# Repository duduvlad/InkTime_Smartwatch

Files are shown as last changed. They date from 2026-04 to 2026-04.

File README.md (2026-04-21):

# InkTime Smartwatch

Un smartwatch open-source cu ecran E-Paper, construit în jurul SoC-ului Nordic nRF52840. Proiectul acoperă etapa de Engineering Validation (EVT): design-ul hardware complet (schematic + PCB), fișierele de fabricație și modelul 3D al ansamblului.

## Cuprins

- [Diagrama Bloc](#diagrama-bloc)
- [Descriere Hardware](#descriere-hardware)
- [Pinout nRF52840](#pinout-nrf52840)
- [Bill of Materials](#bill-of-materials)
- [Estimare Consum Energetic](#estimare-consum-energetic)
- [Decizii de Design și Constrângeri](#decizii-de-design-și-constrângeri)
- [Imagini](#imagini)
- [Structura Repository-ului](#structura-repository-ului)
- [Licență](#licență)

---

## Diagrama Bloc
 
```
                          ┌─────────────────────────────────┐
                          │         nRF52840 (U1)           │
                          │       SoC + BLE Radio           │
                          │                                 │
          ┌───────────────┤ P0.06 (SDA)     P0.02 (SCK)    ├──── SPI ────┐
          │  I2C Bus      │ P0.07 (SCL)     P0.03 (MOSI)   │             │
          │               │                 P0.05 (CS)      │             │
          │               │                 P0.15 (DC)      │             │
          │               │                 P0.16 (RST)     │             │
          │               │                 P0.17 (BUSY)    │             │
          │               │                                 │             │
          │               │ P0.13 ──── SW_UP (buton)        │    ┌────────┴────────┐
          │               │ P0.14 ──── SW_ENTER (buton)     │    │  E-Paper 1.54"  │
          │               │ P1.02 ──── SW_DOWN (buton)      │    │  (via FPC J1)   │
          │               │                                 │    └─────────────────┘
          │               │ P0.12 ──── HAPTIC_EN (DRV2605)  │
          │               │ P0.08 ──── IMU_INT1             │
          │               │ P1.08 ──── IMU_INT2             │
          │               │ P0.10 ──── ALERT (fuel gauge)   │
          │               │ P0.11 ──── PMIC_INT (charger)   │
          │               │ P1.01 ──── EPD_PWR (MOSFET)     │
          │               │                                 │
          │               │ D+/D- ──── USB-C (J4)           │
          │               │ SWDIO/SWDCLK ── Debug (J2)      │
          │               │                                 │
          │               │ ANT (H23) ── Antenă 2.4GHz      │
          │               └─────────────────────────────────┘
          │
     ┌────┴─────────────────────────────────────────────────┐
     │                   Magistrala I2C                      │
     │   (SDA = P0.06, SCL = P0.07, pull-up 3.3kΩ)         │
     ├──────────────┬──────────────┬─────────────┬──────────┤
     │              │              │             │          │
┌────┴────┐  ┌─────┴─────┐  ┌────┴────┐  ┌────┴────┐     │
│ BMA423  │  │ DRV2605   │  │MAX17048 │  │BQ25180  │     │
│  (IC3)  │  │  (IC2)    │  │  (U3)   │  │ (IC1)   │     │
│  IMU    │  │ Haptic    │  │  Fuel   │  │ Charger │     │
│         │  │ Driver    │  │  Gauge  │  │         │     │
└─────────┘  └───────────┘  └────┬────┘  └────┬────┘     │
                                 │             │          │
                            ┌────┴─────────────┴────┐     │
                   ┌───────>│  Baterie LiPo 250mAh  │     │
                   │        │    AKYGA LP502030      │     │
                   │        └───────────┬────────────┘     │
                   │                    │ VREG (SYS)       │
              USB-C (J4)         ┌──────┴──────┐           │
              VBUS ─────────────>│  RT6160     │           │
                                 │  (IC9)      │           │
                                 │  Buck-Boost │           │
                                 └──────┬──────┘           │
                                        │                  │
                                    3.3V Rail ─────────────┘
```

---

## Descriere Hardware

Inima proiectului este **nRF52840** — un SoC cu procesor ARM Cortex-M4F la 64 MHz, 1 MB Flash și 256 KB RAM, plus radio BLE 5.0 integrat. Pe lângă logica principală, el controlează direct toate perifericele de pe placă.

**Managementul energiei** funcționează într-un lanț: USB-C → BQ25180 (charger LiPo) → baterie AKYGA LP502030 (250 mAh, 3.7V) → RT6160 (buck-boost) → 3.3V stabil pentru tot sistemul. Tensiunea bateriei este monitorizată de un fuel gauge MAX17048, care trimite alerte prin I2C și pin-ul ALERT când bateria scade sub praguri configurabile. Charger-ul BQ25180 comunică și el pe I2C, permițând configurarea curentului de încărcare, iar pin-ul !INT semnalează evenimente (încărcare completă, erori termice, etc.).

**Afișajul** este un ecran E-Paper de 1.54" conectat printr-un flex cable (FPC de 24 pini, conector Molex 503480-2400). E-Paper-ul consumă curent doar la refresh și își menține imaginea fără alimentare. Alimentarea display-ului este controlată separat prin P1.01, care comandă un MOSFET P-channel (DMG2305UX-7) — astfel display-ul poate fi oprit complet pentru a economisi energie. Comunicația cu display-ul se face pe SPI, cu pini adiționali de control (DC, RST, BUSY).

**Senzorul de mișcare** BMA421/BMA423 (accelerometru triaxial, 12 biți) este pe magistrala I2C și oferă două ieșiri de întrerupere (INT1 pe P0.08 și INT2 pe P1.08). Este folosit pentru numărarea pașilor, detecția gesturilor (raise-to-wake) și orientarea ecranului. Pin-ul SDO al senzorului este legat la GND prin R3, ceea ce setează adresa I2C la 0x18.

**Feedback haptic**: un motor de vibrații controlat de DRV2605 (driver dedicat cu bibliotecă internă de efecte). Driverul primește comenzi pe I2C și este activat/dezactivat de P0.12 (EN). Ieșirile OUT+ și OUT- merg la motorul haptic (shaker), cu test pad-uri pe placă pentru debugging.

**Butoanele**: trei butoane push (UP, ENTER, DOWN) cu rezistențe de pull-up de 10kΩ la 3.3V și condensatoare de debouncing de 1µF pe fiecare. Sunt active pe LOW — apăsarea trage pinul la GND.

**Conectivitate BLE**: antena ceramică Johanson 2450AT18B100E, conectată la pinul ANT al nRF52840 printr-o rețea de impedanță matching (L1 = 3.9nH, C3 = 1pF, C4 = 1pF). Zona de sub antenă este decupată din toate cele trei planuri de masă.

**Debug/Programare**: interfață SWD (SWDIO, SWDCLK) rutată la conectorul Tag-Connect TC2030-IDC (J2) și la test pad-uri. Pin-ul SWO (P1.00) este disponibil și el pe test pad pentru trace output.

---

## Pinout nRF52840

Tabelul de mai jos detaliază fiecare pin utilizat al microcontroller-ului, cu referința la ball-ul din pachetul aQFN (7x7 mm, 73 pini).

| Pin nRF52840 | Ball | Net / Semnal | Destinație | Notă |
|:---|:---|:---|:---|:---|
| P0.00/XL1 | D2 | P0.00/XL1 | Crystal 32.768 kHz (X2) | Low-frequency clock |
| P0.01/XL2 | F2 | P0.01/XL2 | Crystal 32.768 kHz (X2) | Low-frequency clock |
| P0.02/AIN0 | A12 | SCK | E-Paper SPI Clock | SPI master |
| P0.03/AIN1 | B13 | MOSI | E-Paper SPI Data | SPI master |
| P0.05/AIN3 | K2 | EPD_CS | E-Paper Chip Select | SPI CS, active LOW |
| P0.06 | L1 | SDA | Magistrala I2C - Data | BQ25180, BMA423, DRV2605, MAX17048 |
| P0.07 | M2 | SCL | Magistrala I2C - Clock | Pull-up 3.3kΩ la 3V3 |
| P0.08 | N1 | IMU_INT1 | BMA423 Interrupt 1 | Step counter, gesture detection |
| P0.10/NFC2 | J24 | ALERT | MAX17048 Battery Alert | Active LOW |
| P0.11 | T2 | PMIC_INT | BQ25180 !INT | Semnalizare stare încărcare |
| P0.12 | U1 | HAPTIC_EN | DRV2605 Enable | Activare driver haptic |
| P0.13 | AD8 | SW_UP | Buton UP | Pull-up 10kΩ (R5), debounce 1µF (C30) |
| P0.14 | AC9 | SW_ENTER | Buton ENTER | Pull-up 10kΩ (R8), debounce 1µF (C31) |
| P0.15 | AD10 | EPD_DC | E-Paper Data/Command | HIGH = date, LOW = comandă |
| P0.16 | AC11 | EPD_RST | E-Paper Reset | Active LOW |
| P0.17 | AD12 | EPD_BUSY | E-Paper Busy | HIGH = display ocupat |
| P0.18/RESET | AC13 | RESET | System Reset | Rutat la TP_RESET și J2 |
| P1.00 | AD22 | SWO | Serial Wire Output | Debug trace, rutat la TP_SWO |
| P1.01 | Y23 | EPD_PWR | MOSFET gate (DMG2305UX) | Controlează alimentarea display-ului |
| P1.02 | W24 | SW_DOWN | Buton DOWN | Pull-up 10kΩ (R7), debounce 1µF (C29) |
| P1.08 | P2 | IMU_INT2 | BMA423 Interrupt 2 | Al doilea canal de întrerupere |
| D+ | AD6 | D+ | USB-C Data+ | Prin ESD protection (USBLC6-2SC6Y) |
| D- | AD4 | D- | USB-C Data- | Prin ESD protection (USBLC6-2SC6Y) |
| VBUS | AD2 | VBUS | USB VBUS sense | Detectare conexiune USB |
| SWDIO | AC24 | SWDIO | SWD Debug Data | Rutat la J2 (TC2030) și TP |
| SWDCLK | AA24 | SWDCLK | SWD Debug Clock | Rutat la J2 (TC2030) și TP |
| XC1 | B24 | - | Crystal 32 MHz (X1) | High-frequency clock |
| XC2 | A23 | - | Crystal 32 MHz (X1) | High-frequency clock |
| ANT | H23 | ANT | Rețea matching + Antenă | 2.4 GHz BLE |
| VDDH | Y2 | 3V3 | Alimentare high voltage | 3.3V |
| VDD (multiple) | W1, AD14, B1, A22, AD23 | 3V3 | Alimentare digitală | Fiecare cu condensator de decuplare |
| DCC | B3 | - | DC/DC inductor intern | L2 (10µH) |
| DEC1-6 | diverse | - | Decoupling intern nRF | Condensatoare conform datasheet-ului |

**Pini liberi** (neconectați, disponibili pentru extensii viitoare): P0.04, P0.09, P0.19–P0.31, P1.03–P1.07, P1.09–P1.15.

---

## Bill of Materials

### Componente principale

| Componentă | MFR Part Number | Descriere | JLCPCB Part # | Datasheet |
|:---|:---|:---|:---|:---|
| nRF52840 (U1) | NRF52840-QFAA | SoC BLE 5.0, ARM Cortex-M4F, aQFN-73 | [C190794](https://jlcpcb.com/partdetail/NordicSemicon-NRF52840_QIAAR/C190794) | [Nordic](https://infocenter.nordicsemi.com/pdf/nRF52840_PS_v1.8.pdf) |
| BQ25180 (IC1) | BQ25180YBGR | Charger LiPo, I2C configurabil, BGA-8 | [C3682423](https://jlcpcb.com/partdetail/TexasInstruments-BQ25180YBGR/C3682423) | [TI](https://www.ti.com/lit/ds/symlink/bq25180.pdf) |
| DRV2605 (IC2) | DRV2605YZFR | Haptic driver ERM/LRA, I2C, BGA-9 | [C81079](https://jlcpcb.com/partdetail/TexasInstruments-DRV2605YZFR/C81079) | [TI](https://www.ti.com/lit/ds/symlink/drv2605.pdf) |
| BMA423 (IC3) | BMA423 | Accelerometru triaxial, 12-bit, I2C, LGA-12 | [C437656](https://jlcpcb.com/parts) | [Bosch](https://www.bosch-sensortec.com/media/boschsensortec/downloads/datasheets/bst-bma423-ds000.pdf) |
| RT6160 (IC9) | RT6160AWSC | Buck-Boost DC/DC, I2C, WL-CSP-15 | [C20621404](https://jlcpcb.com/parts) | [Richtek](https://www.richtek.com/assets/product_file/RT6160A/DS6160A-05.pdf) |
| MAX17048 (U3) | MAX17048G+T10 | Fuel gauge LiPo, I2C, TDFN-8 | [C2682616](https://jlcpcb.com/partdetail/MaximIntegrated-MAX17048GT10/C2682616) | [Analog Devices](https://datasheets.maximintegrated.com/en/ds/MAX17048-MAX17049.pdf) |
| Antenă BLE (ANT1) | 2450AT18B100E | Antenă ceramică 2.4 GHz, 1206 | - | [Johanson](https://www.johansontechnology.com/datasheets/2450AT18B100/2450AT18B100.pdf) |
| FPC Connector (J1) | 503480-2400 | Molex 24-pin FPC, 0.5mm pitch | - | [Molex](https://www.molex.com/en-us/products/part-detail/5034802400) |
| USB-C (J4) | KH-TYPE-C-16P | Connector USB-C 16 pini, Kinghelm | - | [Kinghelm](https://www.snapeda.com/parts/KH-TYPE-C-16P/Kinghelm/view-part/) |
| Tag-Connect (J2) | TC2030-IDC | Conector debug SWD, 6 pini | - | [Tag-Connect](https://www.tag-connect.com/product/tc2030-idc) |
| ESD Protection (D3) | USBLC6-2SC6Y | TVS diode array, USB ESD, SOT-23-6 | - | [ST](https://www.st.com/resource/en/datasheet/usblc6-2.pdf) |
| MOSFET P-ch | DMG2305UX-7 | P-MOSFET, 20V/4.2A, SOT-23 | - | [Diodes Inc.](https://www.diodes.com/assets/Datasheets/DMG2305UX.pdf) |
| MOSFET N-ch (Q3) | SI1308EDL-T1-GE3 | N-MOSFET, 30V/1.5A, SC-70 | - | [Vishay](https://www.vishay.com/docs/63399/si1308edl.pdf) |
| Schottky Diodes (D2,D4,D5) | MBR0530 | 30V/0.5A, SOD-123 | - | [ON Semi](https://www.onsemi.com/pdf/datasheet/mbr0520-d.pdf) |
| Butoane (x3) | EVP-AKE31A | Push button, Panasonic | - | [Panasonic](https://industrial.panasonic.com/cdbs/www-data/pdf/ATV0000/ATV0000CE3.pdf) |
| Crystal 32 MHz (X1) | - | XTAL 2016 package | - | - |
| Crystal 32.768 kHz (X2) | - | XTAL 3215 package | - | - |
| Inductor (L7) | FTC252012SR47MBCA | 0.47µH, 2520, TDK | [C5832368](https://jlcpcb.com/partdetail/6763488-FTC252012SR47MBCA/C5832368) | [TDK](https://product.tdk.com/en/search/inductor/inductor/smd/info?part_no=FTC252012SR47MBCA) |

### Pasive (sumarizat)

| Tip | Valori | Capsulă | Cantitate |
|:---|:---|:---|:---|
| Rezistențe 0201 | 0.47Ω, 2.2Ω, 3.3kΩ, 5.1kΩ, 7.68kΩ, 10kΩ | 0201 (0.6x0.3mm) | ~20 buc |
| Condensatoare ≤100nF | 1pF, 12pF, 47nF, 100pF, 100nF | 0201 | ~15 buc |
| Condensatoare >100nF | 1µF, 4.7µF, 10µF, 22µF | 0402 | ~25 buc |
| Inductori | 3.9nH, 10µH, 15µH, 68µH | 0402 | 4 buc |

Lista completă se regăsește în [`Manufacturing/BOM.csv`](Manufacturing/BOM.csv), iar coordonatele de asamblare în [`Manufacturing/PickAndPlace.csv`](Manufacturing/PickAndPlace.csv).

---

## Estimare Consum Energetic

Valorile sunt extrase din datasheet-urile componentelor, pentru modul activ și sleep.

| Componentă | Mod Activ | Mod Sleep / Idle | Notă |
|:---|:---|:---|:---|
| nRF52840 (CPU @ 64MHz) | ~5 mA | ~1.5 µA (System OFF) | CPU + Radio off în sleep |
| nRF52840 (BLE TX) | ~5–8 mA (0 dBm) | - | Transmisie BLE la 0 dBm |
| E-Paper 1.54" | ~15–25 mA (refresh) | ~0 µA | Consum doar la refresh, ~2-3s/refresh |
| BMA423 | ~150 µA | ~14 µA (low-power) | Accelerometru în modul low-power |
| MAX17048 | ~23 µA | ~3 µA (hibernate) | Fuel gauge, citiri periodice |
| BQ25180 | ~1 mA (charging) | ~1 µA (standby) | Consum propriu, fără curentul de încărcare |
| DRV2605 | ~10 mA (activ, cu motor) | ~650 µA (standby) | Standby cu EN LOW |
| RT6160 | ~30 µA (quiescent) | ~30 µA | Eficiența >90% la sarcini mici |

**Estimare viață baterie (250 mAh)**:
- *Standby pur* (ecran static, BLE off, CPU sleep): ~1.5µA + 14µA + 3µA + 1µA + 30µA ≈ **50 µA** → ~5000 ore (~208 zile)
- *Utilizare normală* (10 refresh-uri display/oră, BLE advertising, step counting): consum mediu estimat la **~0.3–0.5 mA** → ~500–830 ore (~21–35 zile)
- *Utilizare intensă* (BLE conectat, refresh-uri frecvente, haptic): consum mediu ~2–5 mA → ~2–5 zile

Aceste estimări sunt teoretice; consumul real va depinde de firmware și pattern-urile de utilizare.

---

## Decizii de Design și Constrângeri

### Reguli PCB respectate
- **Dimensiune PCB**: ~46 x 35 mm (forme octogonale cu decupaje pentru butoane), grosime 1 mm
- **Stackup 4 layere**:
  - **TOP**: componente + rutare + ground pour
  - **Inner 1**: rutare + ground pour
  - **Inner 2**: rutare + ground pour
  - **BOTTOM**: nefolosit (layer-ul a fost lăsat gol conform cerințelor)
- **Componente**: toate amplasate exclusiv pe TOP
- **Trasee de putere** (VBUS, VREG, 3V3, VBAT): width = 0.3 mm, subțiate doar sub BGA-uri unde spațiul impune
- **Trasee de date**: minimum 0.15 mm
- **Fără unghiuri de 90°** pe niciun traseu
- **Condensatoare de decuplare** (100nF): plasate imediat lângă pinii VDD ai fiecărui IC — în cazul nRF52840, câte un condensator per grup de pini VDD (C6, C7, C8, C12, C14 pe 3V3)
- **Via stitching** între cele trei planuri de masă (TOP, Inner 1, Inner 2), cu densitate crescută în zona circuitului radio pentru impedanță scăzută a căii de retur

### Antena
- Antena ceramică (ANT1) este plasată pe marginea de sus a PCB-ului (cea mai depărtată de corpul utilizatorului)
- **Decupaj complet** al cuprului sub antenă pe toate cele trei layere cu ground pour (TOP, Inner 1, Inner 2) — nicio rutare în acea zonă
- Rețea de matching: L1 (3.9nH), C3 (1pF), C4 (1pF) conform recomandărilor Nordic

### Alimentarea display-ului
- Display-ul E-Paper are nevoie de tensiuni de drive mari (±15V–20V) generate intern de circuitul display-ului
- Alimentarea display-ului este comutată printr-un MOSFET P-channel (DMG2305UX-7) controlat de P1.01 prin N-MOSFET Q3 (SI1308EDL)
- Circuitul include diode Schottky (MBR0530) pentru protecția tensiunilor inverse de la pompele de sarcină ale display-ului
- Inductorul L5 (68µH) și condensatoarele asociate filtrează alimentarea display-ului

### Bateria
- AKYGA LP502030: 250 mAh, 3.7V nominal, dimensiuni 32.5 × 21 × 5.5 mm
- Conectată direct la test pad-uri (TP_VBAT, TP_BAT_GND) prin lipire — nu se folosește conectorul JST pentru a economisi spațiu
- Modelul 3D al bateriei este inclus în ansamblul mecanic

### Test Pad-uri
Placa dispune de 14 test pad-uri marcate clar în silkscreen, permițând debugging fără nevoie de conectori:

| Test Pad | Semnal | Scop |
|:---|:---|:---|
| TP_3.3V / TP_3V3 | 3V3 | Verificare alimentare principală |
| TP_VREG | VREG/SYS | Ieșire charger → intrare DC/DC |
| TP_VBAT | VBAT | Tensiune baterie |
| TP_BAT_GND | GND | GND baterie (punct de lipire) |
| TP_GND | GND | Masă de referință |
| TP_SDA | SDA | I2C Data (debugging) |
| TP_SCL | SCL | I2C Clock (debugging) |
| TP_SWDIO | SWDIO | Debug SWD |
| TP_SWDCLK | SWDCLK | Debug SWD |
| TP_SWO | SWO | Serial Wire Output |
| TP_RESET | RESET | Reset manual |
| TP_OP | OUT+ | Ieșire haptic + |
| TP_ON | OUT- | Ieșire haptic - |

### DRC și ERC
- Design-ul trece verificarea DRC cu fișierul de reguli furnizat
- Erori acceptate și documentate:
  - **"Only INPUT pins on NET"** — eroare cosmetică, ignorată conform specificațiilor proiectului
  - **Overlap la test pad-uri** — TP-urile sunt dimensionate generos intenționat pentru ușurința accesului cu sonde
  - **Erori Dimension la butoane și USB-C** — cauzate de decupajele din conturul plăcii, neglijate conform cerințelor

### Silkscreen
- Layer-ul de silkscreen conține doar **designator-urile componentelor** (C1, R5, IC1 etc.), fără valori
- Test pad-urile sunt etichetate cu numele semnalelor pe care le poartă
- Orientarea textelor este uniformă pentru lizibilitate

---

## Imagini

### Schema electrică

**Pagina 1 — MCU, Power, IMU, SWD:**

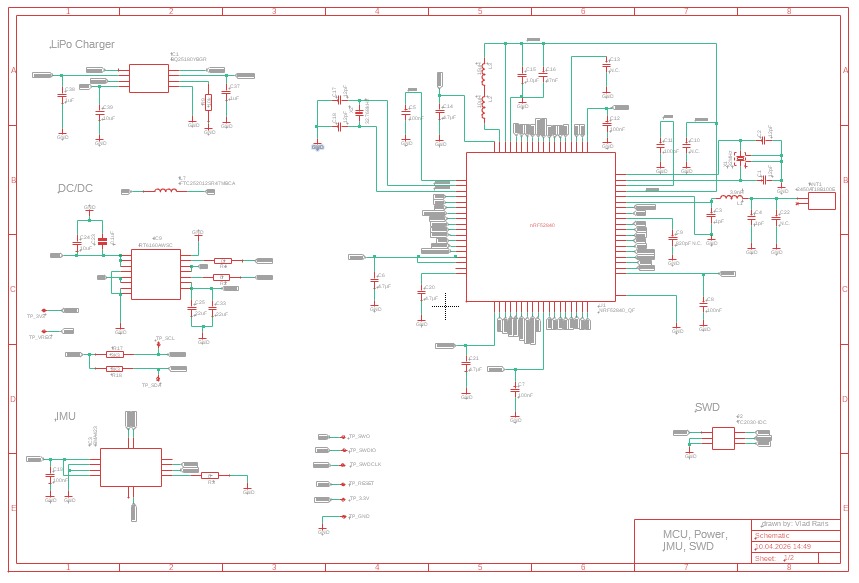
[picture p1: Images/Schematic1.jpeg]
Schematic Page 1


**Pagina 2 — E-Paper, Haptic, Butoane, USB-C:**

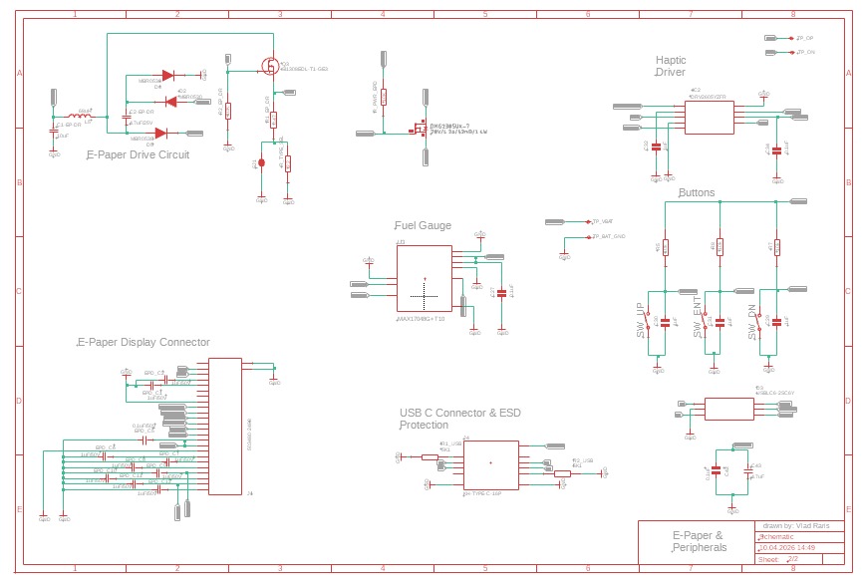
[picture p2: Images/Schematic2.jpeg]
Schematic Page 2


### Layout PCB (TOP)

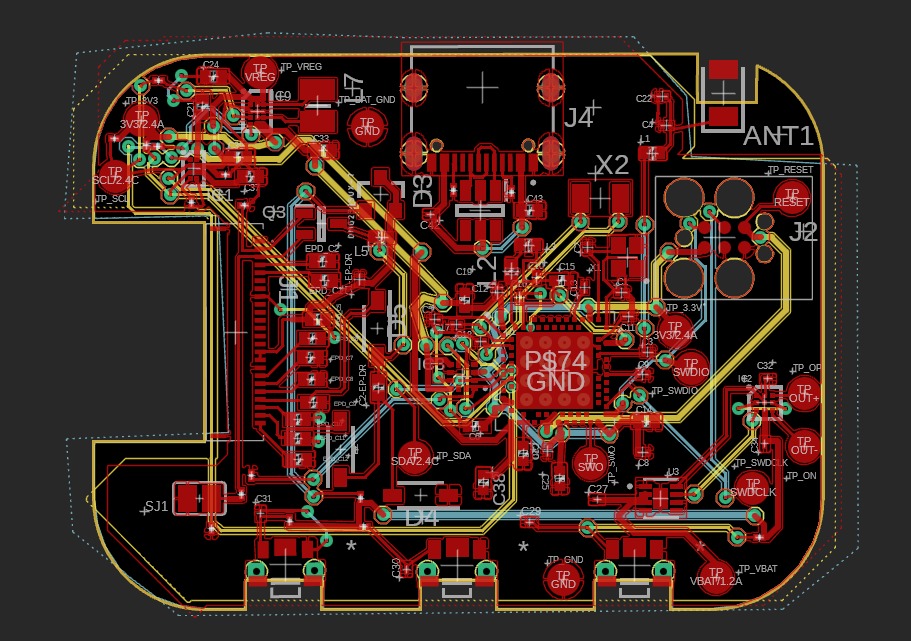
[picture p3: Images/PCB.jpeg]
PCB Layout Top


### PCB3D

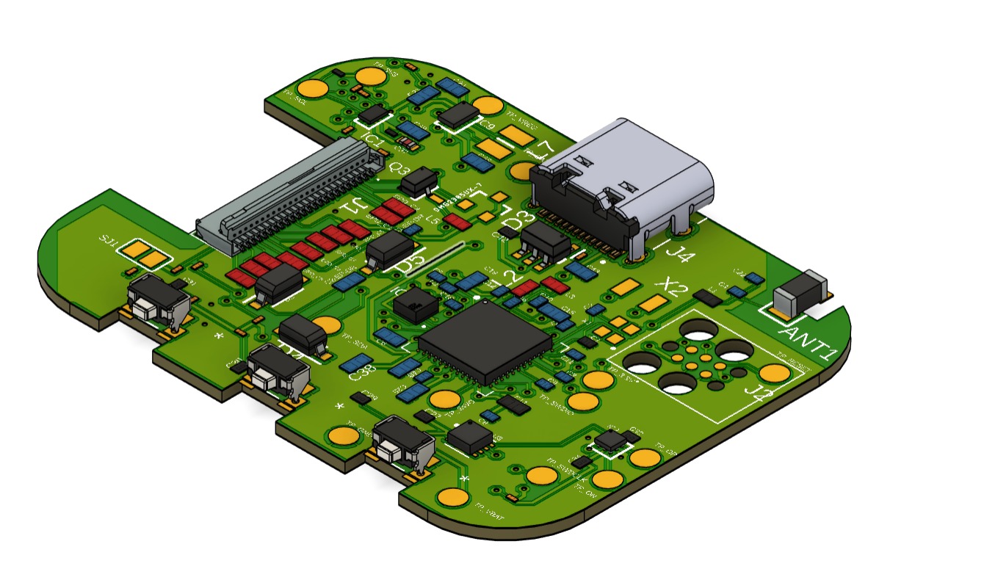
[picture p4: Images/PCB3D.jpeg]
PCB#D


### CARCASA

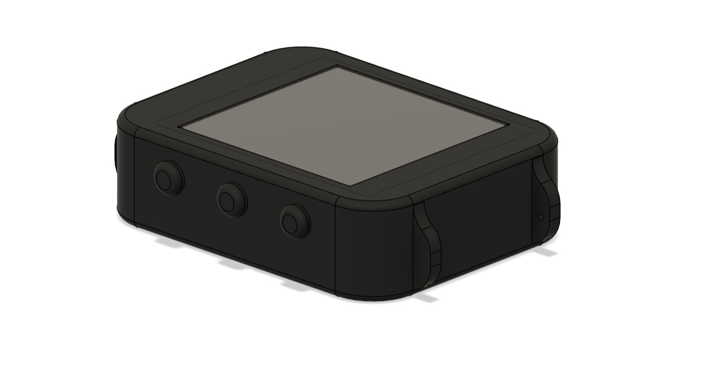
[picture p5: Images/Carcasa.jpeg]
CARCACSA


---

## Structura Repository-ului

```
InkTime_Smartwatch/
├── Hardware/
│   ├── Schematic.sch          # Schema electrică (Eagle/Fusion 360)
│   └── PCB.brd                # Layout-ul PCB (Eagle/Fusion 360)
├── Manufacturing/
│   ├── gerbers.zip            # Fișiere Gerber pentru fabricație PCB
│   ├── BOM.bom                # Bill of Materials complet
│   └── PickAndPlace.cpl       # Coordonate de asamblare SMT
├── Mechanical/
│   ├── WearAwareNewCase.step  # Model 3D complet (PCB + baterie + display + carcasă)
│   └── WearAwareNewCase.3mf   # Model 3D format 3MF
│   └── PCB.step                   # Model 3D al PCB-ului cu componente
├── Images/
│   ├── Schematic1.jpeg       # Schema electrică - MCU, Power, IMU, SWD
│   ├── Schematic2.jpeg # Schema electrică - E-Paper, Haptic, USB-C
│   └── Pcb.jpeg            # Layout PCB - vedere TOP
│   ├── PCB3D.jpeg                 # Randare 3D a PCB-ului
│   └── Carcasa.jpeg               # Randare carcasă
├── LICENSE                    # Apache License 2.0
└── README.md                  # Acest fișier
```

---

## Licență

Proiect open-source, licențiat sub [Apache License 2.0](LICENSE).

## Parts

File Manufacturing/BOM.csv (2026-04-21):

Qty | Value | Device | Package | Parts | Description | ARROW_PART_NUMBER | ARROW_PRICE-STOCK | AVAILABILITY | CHECK_PRICES | COPYRIGHT | DESCRIPTION | DIGI-KEY_PART_NUMBER_1 | DIGI-KEY_PART_NUMBER_2 | DIGI-KEY_PART_NUMBER_3 | HEIGHT | JLCPCB | MANUFACTURER_NAME | MANUFACTURER_PART_NUMBER | MF | MOUSER_PART_NUMBER | MOUSER_PRICE-STOCK | MP | PACKAGE | POPULARITY | PRICE | PROD_ID | PURCHASE-URL | SNAPEDA_LINK | TP_SIGNAL_NAME | VALUE
1 |  | ESP32_C6_LIBRARY_7_JUMPER_SJ | ESP32_C6_LIBRARY_7_JUMPER_SJ | SJ1 | SMD solder JUMPER |  |  |  |  |  |  |  |  |  |  |  |  |  |  |  |  |  |  | 3
3 | 0 | CPF0201D7K68C1_CPF0201D7K68C1 | CPF0201D7K68C1_0201 | R2, R3, R4 | 7.68k 0201 Thin Film Surface Mount Fixed Resistor +/-0.5% 0.031W CPF0201D7K68C1
1 | 0.1uF | GRM011R60J152KE01L_1_GRM011R60J152KE01L | GRM011R60J152KE01L_1_0201 | C23 | Check availability
3 | 0.1uF | GRM011R60J152KE01L_2_GRM011R60J152KE01L | GRM011R60J152KE01L_2_CAPC0201X13N | C27, C34, C42 | Check availability |  |  | In Stock | https://www.snapeda.com/parts/GRM011R60J152KE01L/Murata/view-part/?ref=eda |  | SMD Capacitor X5R(EIA) with Capacitance: 1500pF Tol. 10%. Rated Voltage: 6.3Vdc |  |  |  |  |  |  |  | Murata |  |  | GRM011R60J152KE01L | 0201 Murata |  | None |  |  | https://www.snapeda.com/parts/GRM011R60J152KE01L/Murata/view-part/?ref=snap
1 | 0.1uF/50V | PERFECT_0402_CAP_0402 | PERFECT_0402_0402 | EPD_C5 | 0402 (1005 Metric)
1 | 0.47 | CPF0201D7K68C1_CPF0201D7K68C1 | CPF0201D7K68C1_0201 | R1_EP_DR | 7.68k 0201 Thin Film Surface Mount Fixed Resistor +/-0.5% 0.031W CPF0201D7K68C1
1 | 1.0µF | PERFECT_0402_CAP_0402 | PERFECT_0402_0402 | C15 | 0402 (1005 Metric)
4 | 100nF | NORDIC_NRF_3_CAPACITOR_0201_L | NORDIC_NRF_3_RESC0201_L | C5, C7, C8, C12 | Generic chip capacitor
1 | 100nF | PERFECT_0402_CAP_0402 | PERFECT_0402_0402 | C19 | 0402 (1005 Metric)
1 | 100pF | NORDIC_NRF_3_CAPACITOR_0201_L | NORDIC_NRF_3_RESC0201_L | C11 | Generic chip capacitor
2 | 10K | CPF0201D7K68C1_CPF0201D7K68C1 | CPF0201D7K68C1_0201 | R2_EP_DR, R_PWR_EPD | 7.68k 0201 Thin Film Surface Mount Fixed Resistor +/-0.5% 0.031W CPF0201D7K68C1
4 | 10k | CPF0201D7K68C1_CPF0201D7K68C1 | CPF0201D7K68C1_0201 | R5, R7, R8, R9 | 7.68k 0201 Thin Film Surface Mount Fixed Resistor +/-0.5% 0.031W CPF0201D7K68C1
1 | 10uF | NORDIC_NRF_3_CAPACITOR_0201_L | NORDIC_NRF_3_RESC0201_L | C1-EP-DR | Generic chip capacitor
2 | 10uF | PERFECT_0402_CAP_0402 | PERFECT_0402_0402 | C24, C39 | 0402 (1005 Metric)
1 | 10µH | NORDIC_NRF_2_INDUCTOR_0402_L | NORDIC_NRF_2_RESC0402_L | L2 | Generic chip inductor
4 | 12pF | NORDIC_NRF_3_CAPACITOR_0201_L | NORDIC_NRF_3_RESC0201_L | C1, C2, C17, C18 | Generic chip capacitor
1 | 15µH | NORDIC_NRF_2_INDUCTOR_0402_L | NORDIC_NRF_2_RESC0402_L | L3 | Generic chip inductor
2 | 1pF | NORDIC_NRF_3_CAPACITOR_0201_L | NORDIC_NRF_3_RESC0201_L | C3, C4 | Generic chip capacitor
4 | 1uF | GRM011R60J152KE01L_2_GRM011R60J152KE01L | GRM011R60J152KE01L_2_CAPC0201X13N | C29, C30, C31, C32 | Check availability |  |  | In Stock | https://www.snapeda.com/parts/GRM011R60J152KE01L/Murata/view-part/?ref=eda |  | SMD Capacitor X5R(EIA) with Capacitance: 1500pF Tol. 10%. Rated Voltage: 6.3Vdc |  |  |  |  |  |  |  | Murata |  |  | GRM011R60J152KE01L | 0201 Murata |  | None |  |  | https://www.snapeda.com/parts/GRM011R60J152KE01L/Murata/view-part/?ref=snap
2 | 1uF | PERFECT_0402_CAP_0402 | PERFECT_0402_0402 | C37, C38 | 0402 (1005 Metric)
9 | 1uF/50V | PERFECT_0402_CAP_0402 | PERFECT_0402_0402 | EPD_C1, EPD_C2, EPD_C6, EPD_C7, EPD_C8, EPD_C9, EPD_C10, EPD_C11, EPD_C12 | 0402 (1005 Metric)
1 | 2.2 | CPF0201D7K68C1_CPF0201D7K68C1 | CPF0201D7K68C1_0201 | R_TYPE_SEL | 7.68k 0201 Thin Film Surface Mount Fixed Resistor +/-0.5% 0.031W CPF0201D7K68C1
3 | 2025-10-22_07-23-44_LIBRARY_EVP-AKE31ASW_EVP-AKE31A_PAN | 2025-10-22_07-23-44_LIBRARY_EVP-AKE31ASW_EVP-AKE31A_PAN | 2025-10-22_07-23-44_LIBRARY_SW_EVP-AKE31A_PAN | SW_DN, SW_ENT, SW_UP |  |  |  |  |  | Copyright (C) 2025 Ultra Librarian. All rights reserved. |  | P123437TR-ND | P123437CT-ND | P123437DKR-ND |  |  | Panasonic | EVP-AKE31A
1 | 20V/4.2A/52mO/1.4W | ESP32_C6_LIBRARY_4_ESP32_WROVER_SPARKFUN-DISCRETESEMI_MOSFET_PCH-DMG2305UX-7 | ESP32_C6_LIBRARY_4_ESP32_C6_LIBRARY_4_ESP32_C6_LIBRARY_4_ESP32_C6_LIBRARY_4_ESP32_WROVER_SPARKFUN-DISCRETESEMI_SOT23-3 | DMG2305UX-7 | P-channel MOSFETs |  |  |  |  |  |  |  |  |  |  |  |  |  |  |  |  |  |  |  |  | TRAN-14388 |  |  |  | 20V/4.2A/52mO/1.4W
2 | 22uF | PERFECT_0402_CAP_0402 | PERFECT_0402_0402 | C25, C33 | 0402 (1005 Metric)
1 | 2450AT18B100E | 2450AT18B100E_2450AT18B100E | 2450AT18B100E_ANTC3216X140N | ANT1 | Antennas 2.45GHz ANTENNA | 2450AT18B100E | https://www.arrow.com/en/products/2450at18b100e/johanson-dielectrics?utm_currency=USD&region=nac |  |  |  | Antennas 2.45GHz ANTENNA |  |  |  | 1.4mm |  | JOHANSON TECHNOLOGY | 2450AT18B100E |  | 609-2450AT18B100E | https://www.mouser.co.uk/ProductDetail/Johanson-Technology/2450AT18B100E?qs=yCnrNFeXz%252Bh5MFsFIXGZGA%3D%3D
1 | 3.9nH | NORDIC_NRF_2_INDUCTOR_0402_L | NORDIC_NRF_2_RESC0402_L | L1 | Generic chip inductor
1 | 32.768kHz | NORDIC_NRF_1_XTAL_32KHZ | NORDIC_NRF_1_XTAL_3215_N | X2
1 | 32MHz | NORDIC_NRF_XTAL_32MHZ | NORDIC_NRF_BT-XTAL_2016_N | X1
2 | 3K3 | CPF0201D7K68C1_CPF0201D7K68C1 | CPF0201D7K68C1_0201 | R17, R18 | 7.68k 0201 Thin Film Surface Mount Fixed Resistor +/-0.5% 0.031W CPF0201D7K68C1
1 | 4.7uF | PERFECT_0402_CAP_0402 | PERFECT_0402_0402 | C43 | 0402 (1005 Metric)
1 | 4.7uF/25V | PERFECT_0402_CAP_0402 | PERFECT_0402_0402 | C2-EP-DR | 0402 (1005 Metric)
4 | 4.7µF | PERFECT_0402_CAP_0402 | PERFECT_0402_0402 | C6, C14, C20, C21 | 0402 (1005 Metric)
1 | 47nF | NORDIC_NRF_3_CAPACITOR_0201_L | NORDIC_NRF_3_RESC0201_L | C16 | Generic chip capacitor
1 | 503480-2400 | 503480-2400_503480-2400 | 503480-2400_5034802400 | J1 | FFC & FPC Connectors 0.5mm FPC RA SMT Dual Contact 24Ckt |  |  |  |  |  | FFC & FPC Connectors 0.5mm FPC RA SMT Dual Contact 24Ckt |  |  |  | 1.87mm |  | Molex | 503480-2400 |  | 538-503480-2400 | https://www.mouser.co.uk/ProductDetail/Molex/503480-2400?qs=OAhjpuo3Vu7efIoxFh9AOw%3D%3D
2 | 5K1 | CPF0201D7K68C1_CPF0201D7K68C1 | CPF0201D7K68C1_0201 | R1_USB, R2_USB | 7.68k 0201 Thin Film Surface Mount Fixed Resistor +/-0.5% 0.031W CPF0201D7K68C1
1 | 68uH | NORDIC_NRF_2_INDUCTOR_0402_L | NORDIC_NRF_2_RESC0402_L | L5 | Generic chip inductor
1 | 820pF N.C. | NORDIC_NRF_3_CAPACITOR_0201_L | NORDIC_NRF_3_RESC0201_L | C9 | Generic chip capacitor
1 | BMA423 | BMA423_BMA423 | BMA423_BMA423 | IC3 | Accelerometers Triaxial low-g 12bit Acceleration Sensor | BMA423 | https://www.arrow.com/en/products/bma423/bosch |  |  |  | Accelerometers Triaxial low-g 12bit Acceleration Sensor |  |  |  | 1mm |  | BOSCH | BMA423 |  | 262-BMA423 | https://www.mouser.co.uk/ProductDetail/Bosch-Sensortec/BMA423?qs=HXFqYaX1Q2xC%252BSgeGoX3mg%3D%3D
1 | BQ25180YBGR | BQ25180YBGR_BQ25180YBGR | BQ25180YBGR_BGA8C40P2X4_100X155X50 | IC1 | Charger IC Lithium Ion/Polymer, Lithium Iron Phosphate 8-DSBGA (1.6x1.1) | BQ25180YBGR | https://www.arrow.com/en/products/bq25180ybgr/texas-instruments?utm_currency=USD&region=nac |  |  |  | Charger IC Lithium Ion/Polymer | Lithium Iron Phosphate 8-DSBGA (1.6x1.1) |  |  |  | 0.5mm |  | Texas Instruments | BQ25180YBGR |  | 595-BQ25180YBGR | https://www.mouser.co.uk/ProductDetail/Texas-Instruments/BQ25180YBGR?qs=doiCPypUmgEWjAK%252BJAX6Tw%3D%3D
1 | DRV2605YZFR | DRV2605YZFR_DRV2605YZFR | DRV2605YZFR_BGA9C50P3X3_144X144X62 | IC2 | Haptic Driver for ERM/LRA with Built-In Library and Smart Loop Architecture | DRV2605YZFR | https://www.arrow.com/en/products/drv2605yzfr/texas-instruments?region=nac |  |  |  | Haptic Driver for ERM/LRA with Built-In Library and Smart Loop Architecture |  |  |  | 0.625mm |  | Texas Instruments | DRV2605YZFR
1 | FTC252012SR47MBCA | MLP2016SR47MT0S1_FTC252012SR47MBCA | MLP2016SR47MT0S1_INDC2016X100N | L7 | SMD / SMT Inductors (Coils), L=0.47?H, L x W x T : |  |  |  |  |  | SMD / SMT Inductors (Coils) | L=0.47?H | L x W x T : |  |  |  | 1mm | https://jlcpcb.com/partdetail/6763488-FTC252012SR47MBCA/C5832368 | TDK | FTC252012SR47MBCA
14 | HECTOR_WATCH_1_TPTP20R | HECTOR_WATCH_1_TPTP20R | HECTOR_WATCH_1_TP20R | TP_3.3V, TP_3V3, TP_BAT_GND, TP_GND, TP_ON, TP_OP, TP_RESET, TP_SCL, TP_SDA, TP_SWDCLK, TP_SWDIO, TP_SWO, TP_VBAT, TP_VREG | Test pad |  |  |  |  |  |  |  |  |  |  |  |  |  |  |  |  |  |  | 2
1 | KH-TYPE-C-16P | KH-TYPE-C-16P_KH-TYPE-C-16P | KH-TYPE-C-16P_KINGHELM_KH-TYPE-C-16P | J4 | Check availability |  |  | Not in stock | https://www.snapeda.com/parts/KH-TYPE-C-16P/Kinghelm/view-part/?ref=eda |  |  |  |  |  |  |  |  |  | kinghelm |  |  | KH-TYPE-C-16P | None |  | None |  |  | https://www.snapeda.com/parts/KH-TYPE-C-16P/Kinghelm/view-part/?ref=snap
1 | MAX17048G+T10 | ESP32_C6_LIBRARY_MAX17048G+T10 | ESP32_C6_LIBRARY_SON50P200X200X80-9N | U3 | Check availability |  |  | In Stock | https://www.snapeda.com/parts/MAX17048G+T10/Analog+Devices/view-part/?ref=eda |  | 3µA 1-Cell/2-Cell Fuel Gauge with ModelGauge |  |  |  |  |  |  |  | Analog Devices |  |  | MAX17048G+T10 | TDFN-8 Maxim |  | None |  | https://www.snapeda.com/api/url_track_click_mouser/?unipart_id=329239&manufacturer=Analog Devices&part_name=MAX17048G+T10&search_term=None | https://www.snapeda.com/parts/MAX17048G+T10/Analog+Devices/view-part/?ref=snap
3 | MBR0530 | ESP32_C6_LIBRARY_5_MBR0530 | ESP32_C6_LIBRARY_5_SOD3716X135N | D2, D4, D5 | ON SEMICONDUCTOR - MBR0530 - DIODE, SCHOTTKY, 0.5A, 30V, SOD-123 |  |  | In Stock | https://www.snapeda.com/parts/MBR0530/Onsemi/view-part/?ref=eda |  | Diode Schottky 30 V 500mA Surface Mount SOD-123 |  |  |  |  |  |  |  | ON Semiconductor |  |  | MBR0530 | SOD-123-2 ON Semiconductor |  | None |  | https://www.snapeda.com/api/url_track_click_mouser/?unipart_id=179458&manufacturer=ON Semiconductor&part_name=MBR0530&search_term=None | https://www.snapeda.com/parts/MBR0530/Onsemi/view-part/?ref=snap
3 | N.C. | NORDIC_NRF_3_CAPACITOR_0201_L | NORDIC_NRF_3_RESC0201_L | C10, C13, C22 | Generic chip capacitor
1 | NRF52840_QF | NORDIC_NRF_4_NRF52840_QF | NORDIC_NRF_4_AQFN50P700X700X85_HS-74N | U1 | nRF52840
1 | RT6160AWSC | RT6160AWSC_RT6160AWSC | RT6160AWSC_BGA15C40P3X5_140X230X60 | IC9 | Buck-Boost Regulator Positive Output Step-Up/Step-Down I2C DC-DC Controller IC 15-WL-CSP (BSC) (1.4x2.3) |  |  |  |  |  | Buck-Boost Regulator Positive Output Step-Up/Step-Down I2C DC-DC Controller IC 15-WL-CSP (BSC) (1.4x2.3) |  |  |  | 0.6mm |  | RICHTEK | RT6160AWSC |  | 835-RT6160AWSC | https://www.mouser.co.uk/ProductDetail/Richtek/RT6160AWSC?qs=amGC7iS6iy%2FLd9PSoixZXQ%3D%3D
1 | SI1308EDL-T1-GE3 | ESP32_C6_LIBRARY_6_SI1308EDL-T1-GE3 | ESP32_C6_LIBRARY_6_SOT65P210X110-3N | Q3 | MOSFET N-Ch 30V 1.5A TrenchFET SC70 Vishay Si1308EDL-T1-GE3 N-channel MOSFET Transistor, 1.5 A, 30 V, 3-Pin SC-70 |  |  | In Stock | https://www.snapeda.com/parts/SI1308EDL-T1-GE3/Vishay+Siliconix/view-part/?ref=eda |  | Si1308EDL-T1-GE3 N-channel MOSFET Transistor | 1.5 A | 30 V | 3-Pin SC-70 | Siliconix / Vishay SI1308EDL-T1-GE3 |  |  |  |  |  |  |  | Vishay Siliconix |  |  | SI1308EDL-T1-GE3 | SOT-323 Vishay Semiconductor |  | None |  | https://www.snapeda.com/api/url_track_click_mouser/?unipart_id=274603&manufacturer=Vishay Siliconix&part_name=SI1308EDL-T1-GE3&search_term=None
1 | TC2030-IDC | TC2030-IDC_TC2030-IDC | TC2030-IDC_TC2030IDC | J2 | CABLE ADAPTER 6 POS |  |  |  |  |  | CABLE ADAPTER 6 POS |  |  |  | 19mm |  | Tag Connect | TC2030-IDC
1 | USBLC6-2SC6Y | ESP32_C6_LIBRARY_3_USBLC6-2SC6Y | ESP32_C6_LIBRARY_3_SOT95P280X145-6N | D3 | Low Cap. ESD Protection Auto SOT-23-6 STMicroelectronics USBLC6-2SC6Y, Dual Uni-Directional TVS Diode Array, 6-Pin SOT-23 |  |  | In Stock | https://www.snapeda.com/parts/USBLC6-2SC6Y/STMicroelectronics/view-part/?ref=eda |  | 17V Clamp 5A (8/20µs) Ipp Tvs Diode Surface Mount SOT-23-6 |  |  |  |  |  |  |  | STMicroelectronics |  |  | USBLC6-2SC6Y | SOT-23-6 STMicroelectronics |  | None |  |  | https://www.snapeda.com/parts/USBLC6-2SC6Y/STMicroelectronics/view-part/?ref=snap

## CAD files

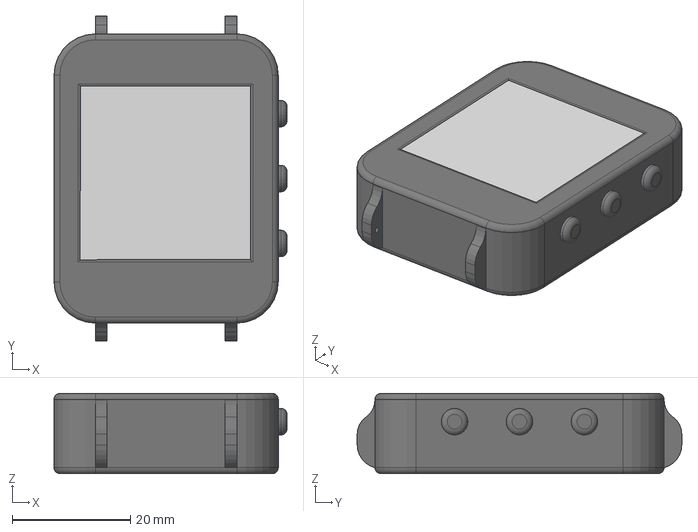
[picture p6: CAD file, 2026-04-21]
Mechanical/WearAwareNewCase.step
39.5 x 55.0 x 13.6 mm

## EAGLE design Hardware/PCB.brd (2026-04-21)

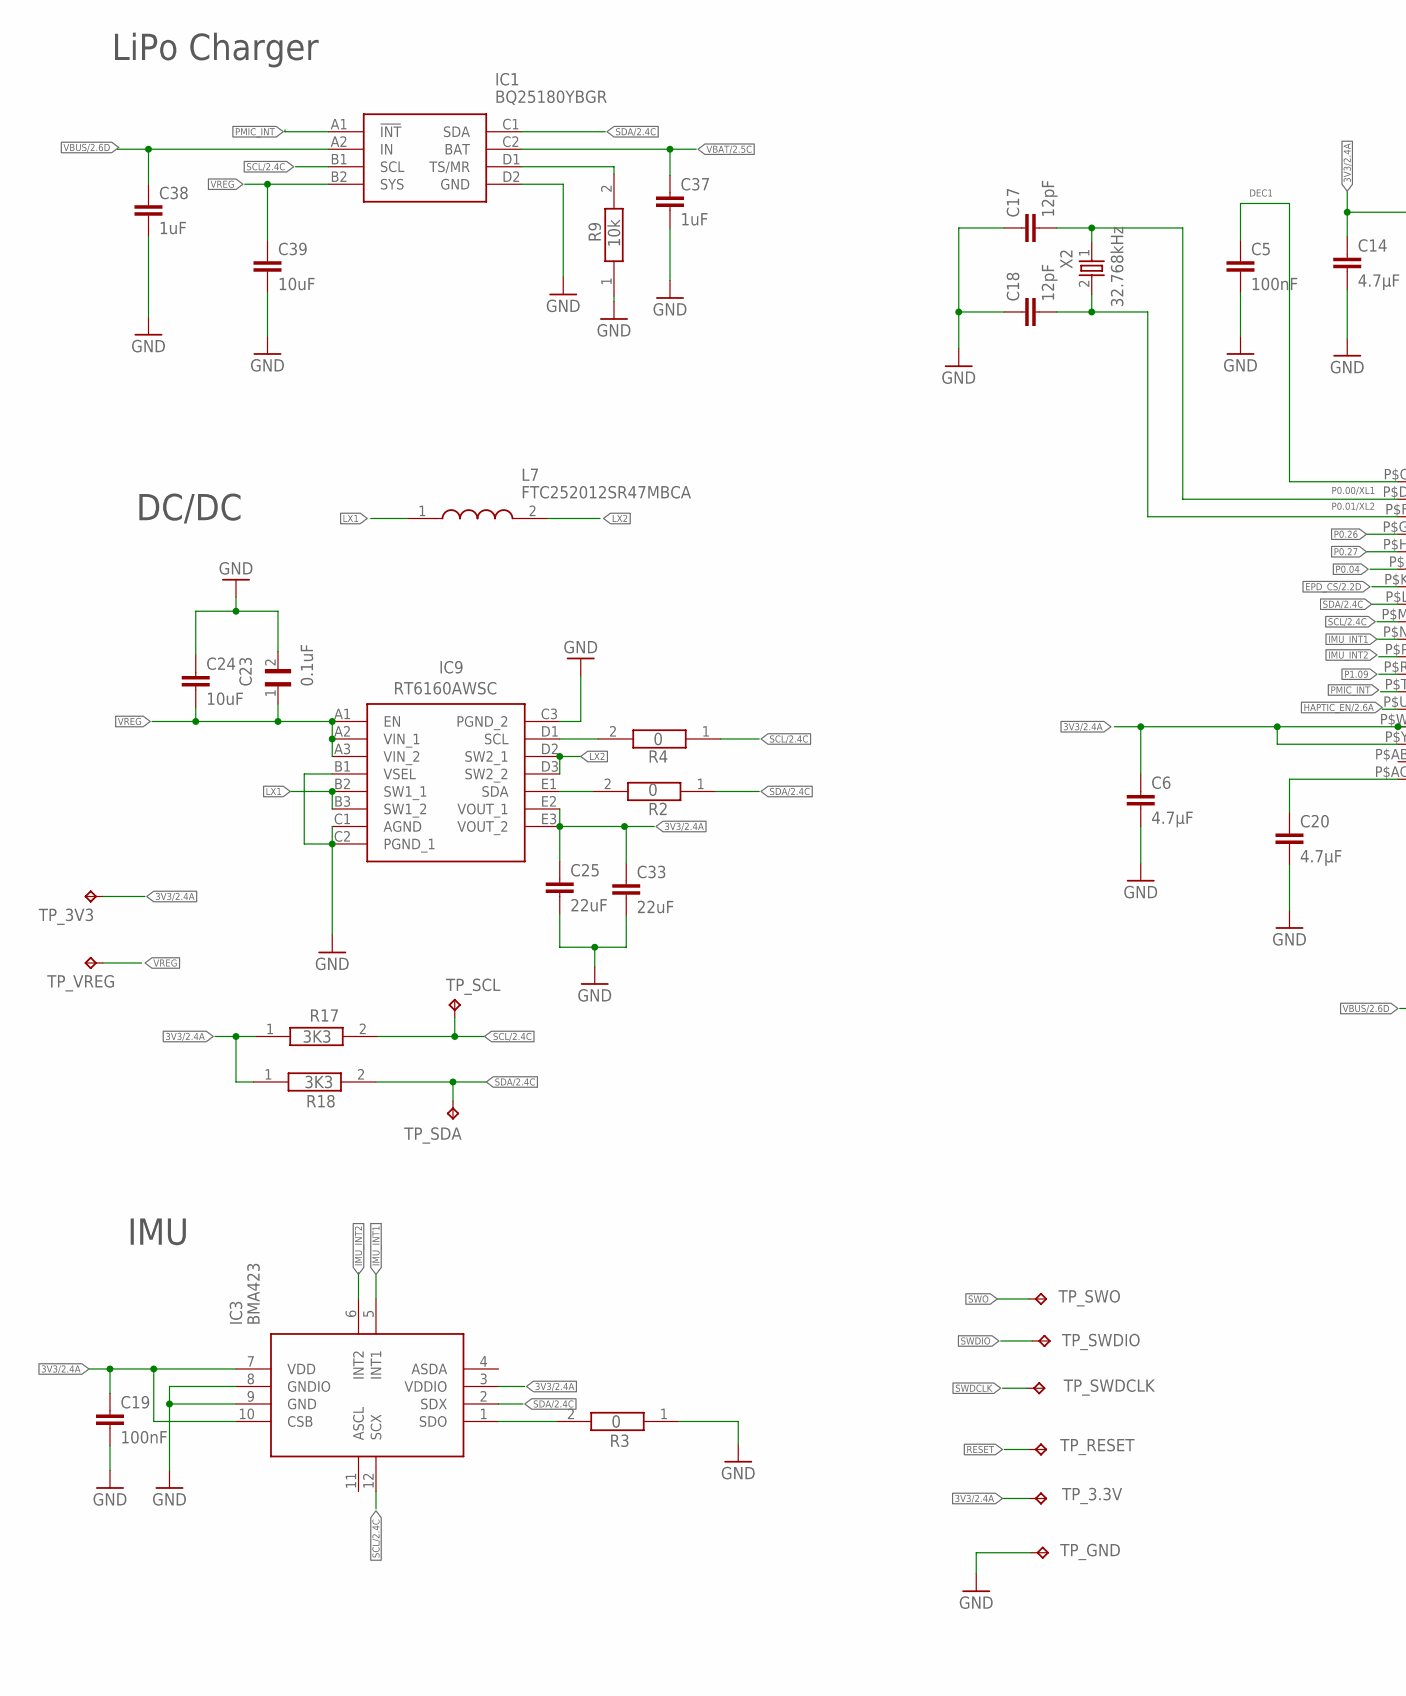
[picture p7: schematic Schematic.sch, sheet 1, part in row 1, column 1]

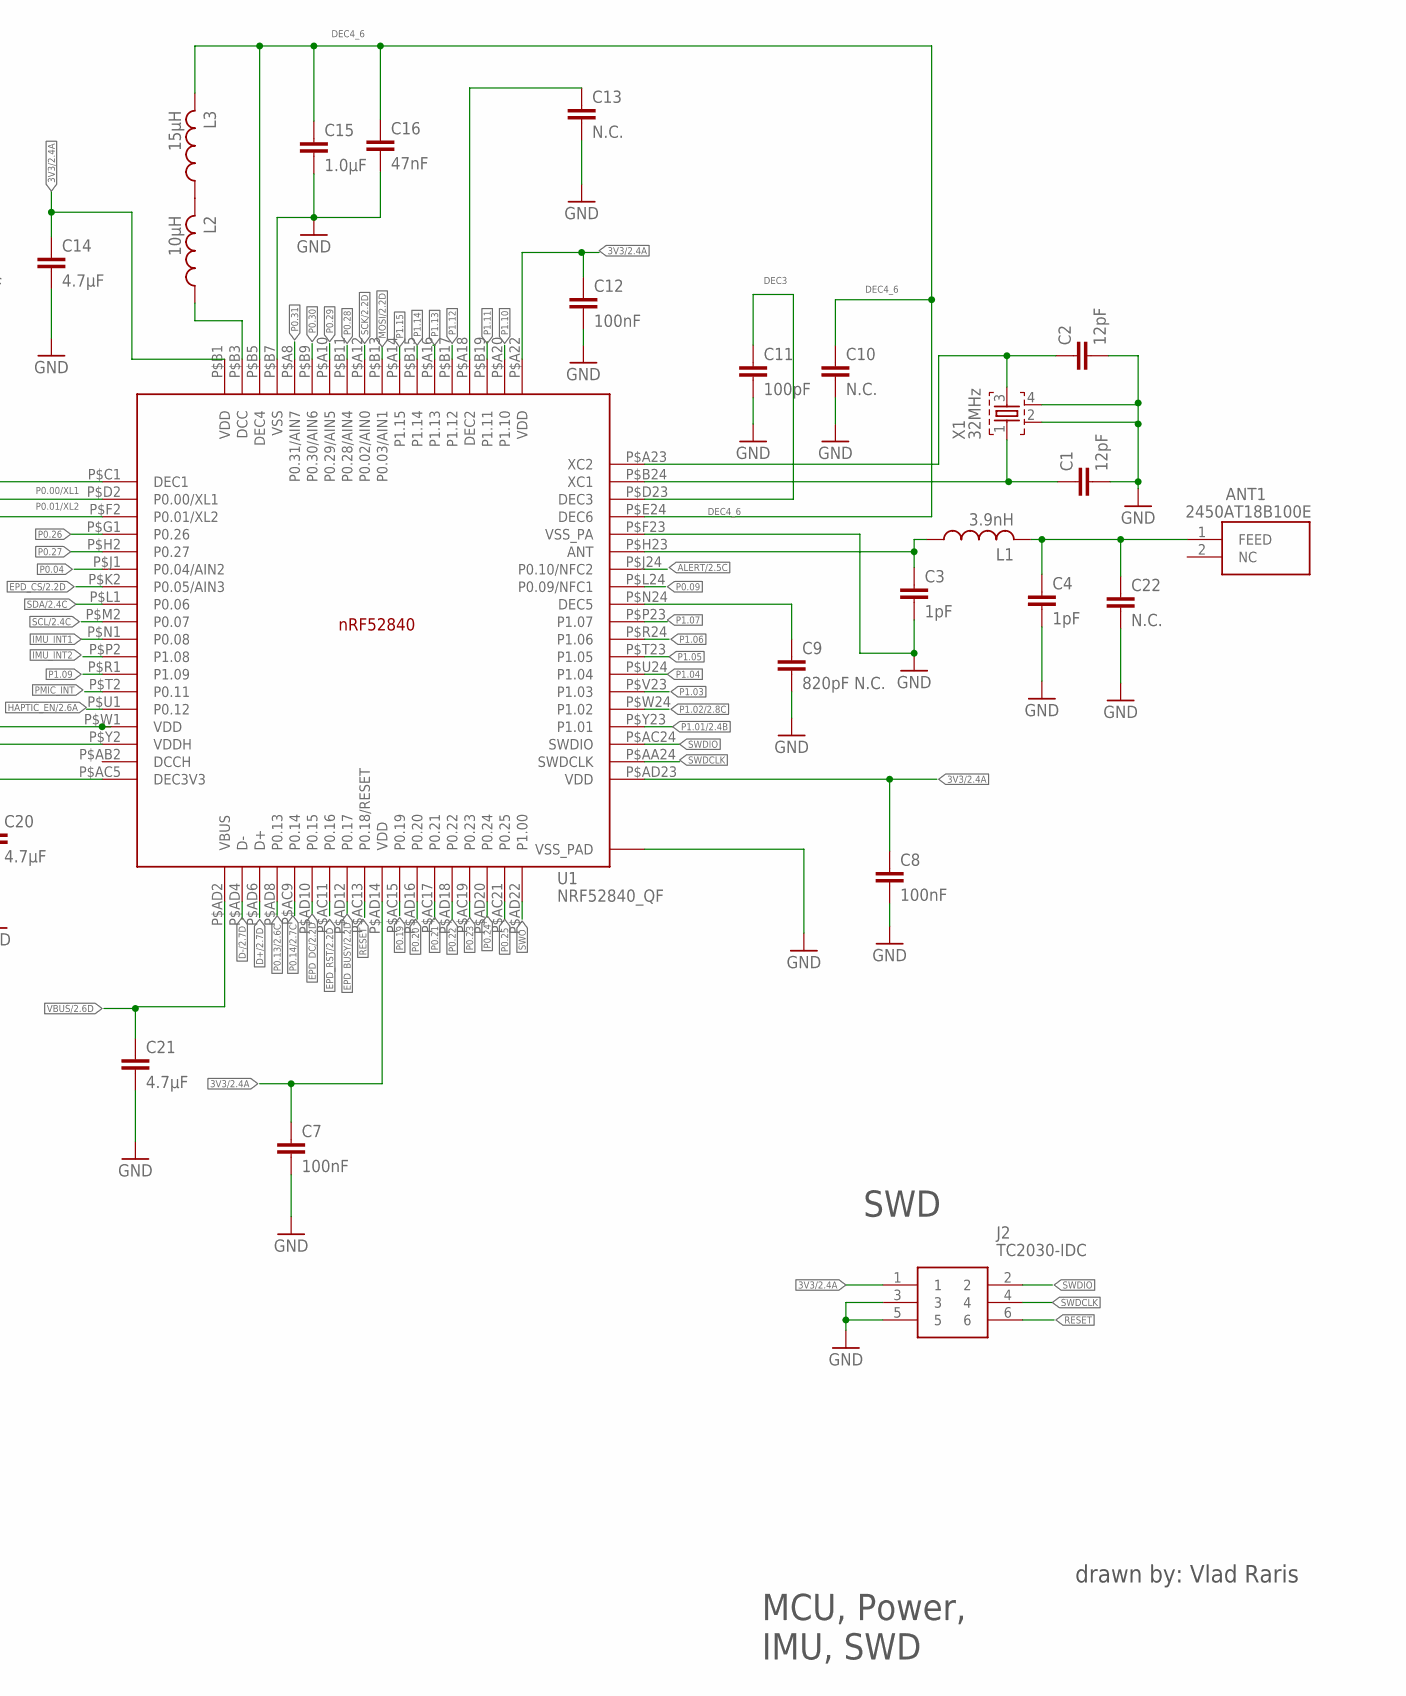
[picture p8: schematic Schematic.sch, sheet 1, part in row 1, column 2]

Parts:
ANT1: 2450AT18B100E; 2450AT18B100E_ANTC3216X140N
C1, C2, C17, C18: 12pF; NORDIC_NRF_3_RESC0201_L
C3, C4: 1pF; NORDIC_NRF_3_RESC0201_L
C5, C7, C8, C12: 100nF; NORDIC_NRF_3_RESC0201_L
C6, C14, C20, C21: 4.7μF; PERFECT_0402_0402
C9: 820pF N.C.; NORDIC_NRF_3_RESC0201_L
C10, C13, C22: N.C.; NORDIC_NRF_3_RESC0201_L
C11: 100pF; NORDIC_NRF_3_RESC0201_L
C15: 1.0μF; PERFECT_0402_0402
C16: 47nF; NORDIC_NRF_3_RESC0201_L
C19: 100nF; PERFECT_0402_0402
C23: 0.1uF; GRM011R60J152KE01L_1_0201
C24, C39: 10uF; PERFECT_0402_0402
C25, C33: 22uF; PERFECT_0402_0402
C37, C38: 1uF; PERFECT_0402_0402
IC1: BQ25180YBGR; BQ25180YBGR_BGA8C40P2X4_100X155X50
IC3: BMA423; BMA423_BMA423
IC9: RT6160AWSC; RT6160AWSC_BGA15C40P3X5_140X230X60
J2: TC2030-IDC; TC2030-IDC_TC2030IDC
L1: 3.9nH; NORDIC_NRF_2_RESC0402_L
L2: 10μH; NORDIC_NRF_2_RESC0402_L
L3: 15μH; NORDIC_NRF_2_RESC0402_L
L7: FTC252012SR47MBCA; MLP2016SR47MT0S1_INDC2016X100N
R2, R3, R4: 0; CPF0201D7K68C1_0201
R9: 10k; CPF0201D7K68C1_0201
R17, R18: 3K3; CPF0201D7K68C1_0201
TP_3.3V, TP_3V3: HECTOR_WATCH_1_TPTP20R; HECTOR_WATCH_1_TP20R
TP_GND: HECTOR_WATCH_1_TPTP20R; HECTOR_WATCH_1_TP20R
TP_RESET: HECTOR_WATCH_1_TPTP20R; HECTOR_WATCH_1_TP20R
TP_SCL: HECTOR_WATCH_1_TPTP20R; HECTOR_WATCH_1_TP20R
TP_SDA: HECTOR_WATCH_1_TPTP20R; HECTOR_WATCH_1_TP20R
TP_SWDCLK: HECTOR_WATCH_1_TPTP20R; HECTOR_WATCH_1_TP20R
TP_SWDIO: HECTOR_WATCH_1_TPTP20R; HECTOR_WATCH_1_TP20R
TP_SWO: HECTOR_WATCH_1_TPTP20R; HECTOR_WATCH_1_TP20R
TP_VREG: HECTOR_WATCH_1_TPTP20R; HECTOR_WATCH_1_TP20R
U1: NRF52840_QF; NORDIC_NRF_4_AQFN50P700X700X85_HS-74N
X1: 32MHz; NORDIC_NRF_BT-XTAL_2016_N
X2: 32.768kHz; NORDIC_NRF_1_XTAL_3215_N

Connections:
3V3/2.4A: C6.1, C7.1, C8.1, C12.1, C14.1, C19.1, C25.1, C33.1, IC3.3 (VDDIO), IC3.7 (VDD), IC3.10 (CSB), IC9.E2 (VOUT_1), IC9.E3 (VOUT_2), J2.1, R17.1, R18.1, TP_3.3V.TP, TP_3V3.TP, U1.P$A22 (VDD), U1.P$AD14 (VDD), U1.P$AD23 (VDD), U1.P$B1 (VDD), U1.P$W1 (VDD), U1.P$Y2 (VDDH)
ALERT/2.5C: U1.P$J24 (P0.10/NFC2)
D+/2.7D: U1.P$AD6 (D+)
D-/2.7D: U1.P$AD4 (D-)
DEC1: C5.1, U1.P$C1 (DEC1)
DEC3: C11.1, U1.P$D23 (DEC3)
DEC4_6: C10.1, C15.1, C16.1, L3.2, U1.P$B5 (DEC4), U1.P$E24 (DEC6)
EPD_BUSY/2.2D: U1.P$AD12 (P0.17)
EPD_CS/2.2D: U1.P$K2 (P0.05/AIN3)
EPD_DC/2.2D: U1.P$AD10 (P0.15)
EPD_RST/2.2D: U1.P$AC11 (P0.16)
GND: C1.2, C2.2, C3.2, C4.2, C5.2, C6.2, C7.2, C8.2, C9.2, C10.2, C11.2, C12.2, C13.2, C14.2, C15.2, C16.2, C17.1, C18.1, C19.2, C20.2, C21.2, C22.2, C23.2, C24.1, C25.2, C33.2, C37.2, C38.2, C39.2, IC1.D2 (GND), IC3.8 (GNDIO), IC3.9 (GND), IC9.B1 (VSEL), IC9.C1 (AGND), IC9.C2 (PGND_1), IC9.C3 (PGND_2), J2.3, J2.5, R3.1, R9.1, TP_GND.TP, U1.P$74 (VSS_PAD), U1.P$75 (VSS_PAD), U1.P$76 (VSS_PAD), U1.P$77 (VSS_PAD), U1.P$78 (VSS_PAD), U1.P$79 (VSS_PAD), U1.P$80 (VSS_PAD), U1.P$81 (VSS_PAD), U1.P$82 (VSS_PAD), U1.P$83 (VSS_PAD), U1.P$84 (VSS_PAD), U1.P$85 (VSS_PAD), U1.P$86 (VSS_PAD), U1.P$87 (VSS_PAD), U1.P$88 (VSS_PAD), U1.P$89 (VSS_PAD), U1.P$90 (VSS_PAD), U1.P$B7 (VSS), U1.P$F23 (VSS_PA), X1.2, X1.4; also elsewhere on the board
HAPTIC_EN/2.6A: U1.P$U1 (P0.12)
IMU_INT1: IC3.5 (INT1), U1.P$N1 (P0.08)
IMU_INT2: IC3.6 (INT2), U1.P$P2 (P1.08)
LX1: IC9.B2 (SW1_1), IC9.B3 (SW1_2), L7.1
LX2: IC9.D2 (SW2_1), IC9.D3 (SW2_2), L7.2
MOSI/2.2D: U1.P$B13 (P0.03/AIN1)
unnamed: IC1.D1 (TS/MR), R9.2
unnamed: IC9.D1 (SCL), R4.2
unnamed: IC9.E1 (SDA), R2.2
unnamed: C20.1, U1.P$AC5 (DEC3V3)
unnamed: C9.1, U1.P$N24 (DEC5)
unnamed: C3.1, L1.1, U1.P$H23 (ANT)
unnamed: IC3.1 (SDO), R3.2
unnamed: C1.1, U1.P$B24 (XC1), X1.1
unnamed: C13.1, U1.P$A18 (DEC2)
unnamed: ANT1.1 (FEED), C4.1, C22.1, L1.2
unnamed: C2.1, U1.P$A23 (XC2), X1.3
unnamed: L2.2, L3.1
unnamed: L2.1, U1.P$B3 (DCC)
P0.00/XL1: C17.2, U1.P$D2 (P0.00/XL1), X2.1
P0.01/XL2: C18.2, U1.P$F2 (P0.01/XL2), X2.2
P0.04: U1.P$J1 (P0.04/AIN2)
P0.09: U1.P$L24 (P0.09/NFC1)
P0.13/2.6C: U1.P$AD8 (P0.13)
P0.14/2.7C: U1.P$AC9 (P0.14)
P0.19: U1.P$AC15 (P0.19)
P0.20: U1.P$AD16 (P0.20)
P0.21: U1.P$AC17 (P0.21)
P0.22: U1.P$AD18 (P0.22)
P0.23: U1.P$AC19 (P0.23)
P0.24: U1.P$AD20 (P0.24)
P0.25: U1.P$AC21 (P0.25)
P0.26: U1.P$G1 (P0.26)
P0.27: U1.P$H2 (P0.27)
P0.28: U1.P$B11 (P0.28/AIN4)
P0.29: U1.P$A10 (P0.29/AIN5)
P0.30: U1.P$B9 (P0.30/AIN6)
P0.31: U1.P$A8 (P0.31/AIN7)
P1.01/2.4B: U1.P$Y23 (P1.01)
P1.02/2.8C: U1.P$W24 (P1.02)
P1.03: U1.P$V23 (P1.03)
P1.04: U1.P$U24 (P1.04)
P1.05: U1.P$T23 (P1.05)
P1.06: U1.P$R24 (P1.06)
P1.07: U1.P$P23 (P1.07)
P1.09: U1.P$R1 (P1.09)
P1.10: U1.P$A20 (P1.10)
P1.11: U1.P$B19 (P1.11)
P1.12: U1.P$B17 (P1.12)
P1.13: U1.P$A16 (P1.13)
P1.14: U1.P$B15 (P1.14)
P1.15: U1.P$A14 (P1.15)
PMIC_INT: IC1.A1 (!INT), U1.P$T2 (P0.11)
RESET: J2.6, TP_RESET.TP, U1.P$AC13 (P0.18/RESET)
SCK/2.2D: U1.P$A12 (P0.02/AIN0)
SCL/2.4C: IC1.B1 (SCL), IC3.12 (SCX), R4.1, R17.2, TP_SCL.TP, U1.P$M2 (P0.07)
SDA/2.4C: IC1.C1 (SDA), IC3.2 (SDX), R2.1, R18.2, TP_SDA.TP, U1.P$L1 (P0.06)
SWDCLK: J2.4, TP_SWDCLK.TP, U1.P$AA24 (SWDCLK)
SWDIO: J2.2, TP_SWDIO.TP, U1.P$AC24 (SWDIO)
SWO: TP_SWO.TP, U1.P$AD22 (P1.00)
VBAT/2.5C: C37.1, IC1.C2 (BAT)
VBUS/2.6D: C21.1, C38.1, IC1.A2 (IN), U1.P$AD2 (VBUS)
VREG: C23.1, C24.2, C39.1, IC1.B2 (SYS), IC9.A1 (EN), IC9.A2 (VIN_1), IC9.A3 (VIN_2), TP_VREG.TP

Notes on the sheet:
LiPo Charger
DC/DC
SWD
IMU
drawn by: Vlad Raris
MCU, Power, IMU, SWD

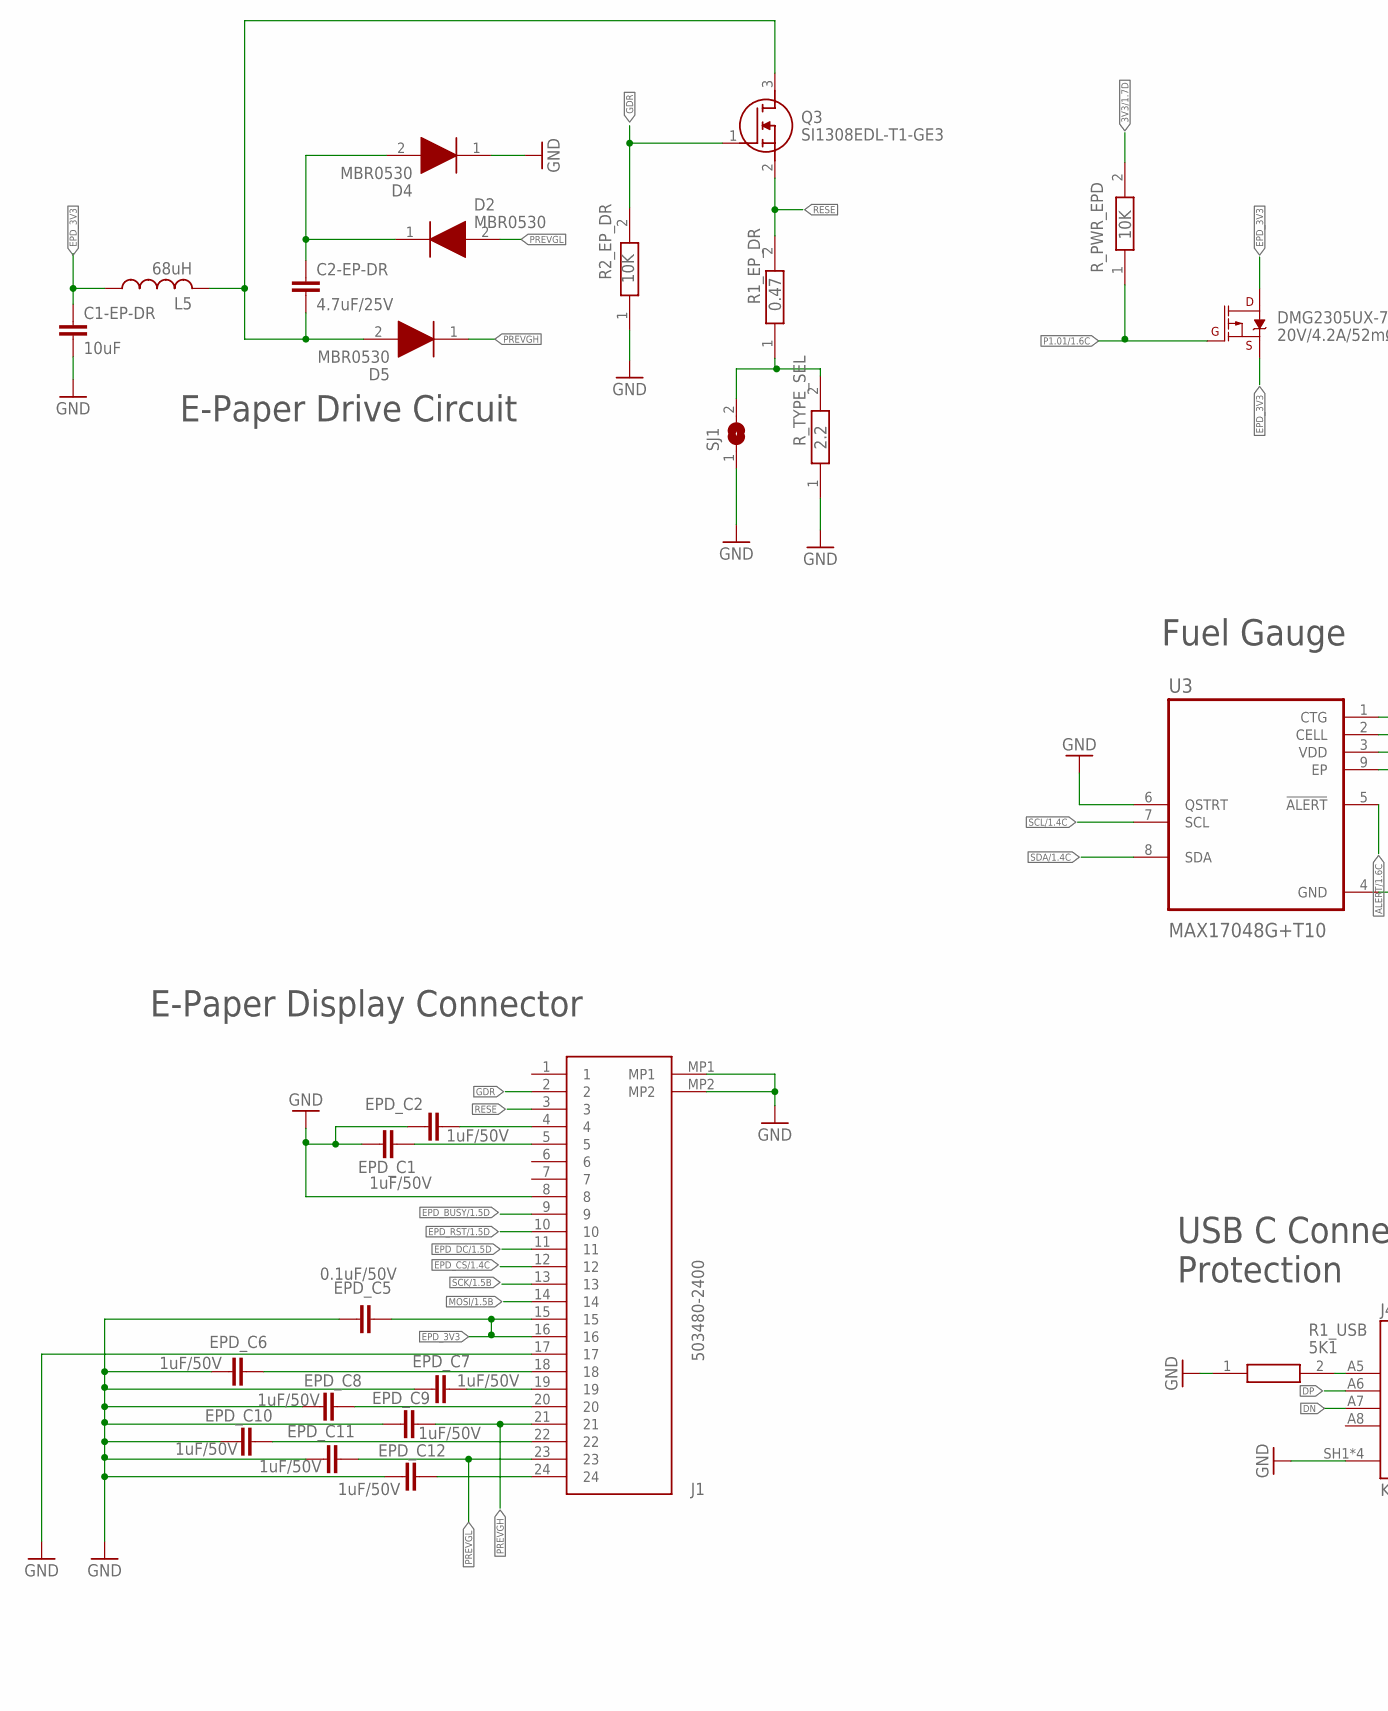
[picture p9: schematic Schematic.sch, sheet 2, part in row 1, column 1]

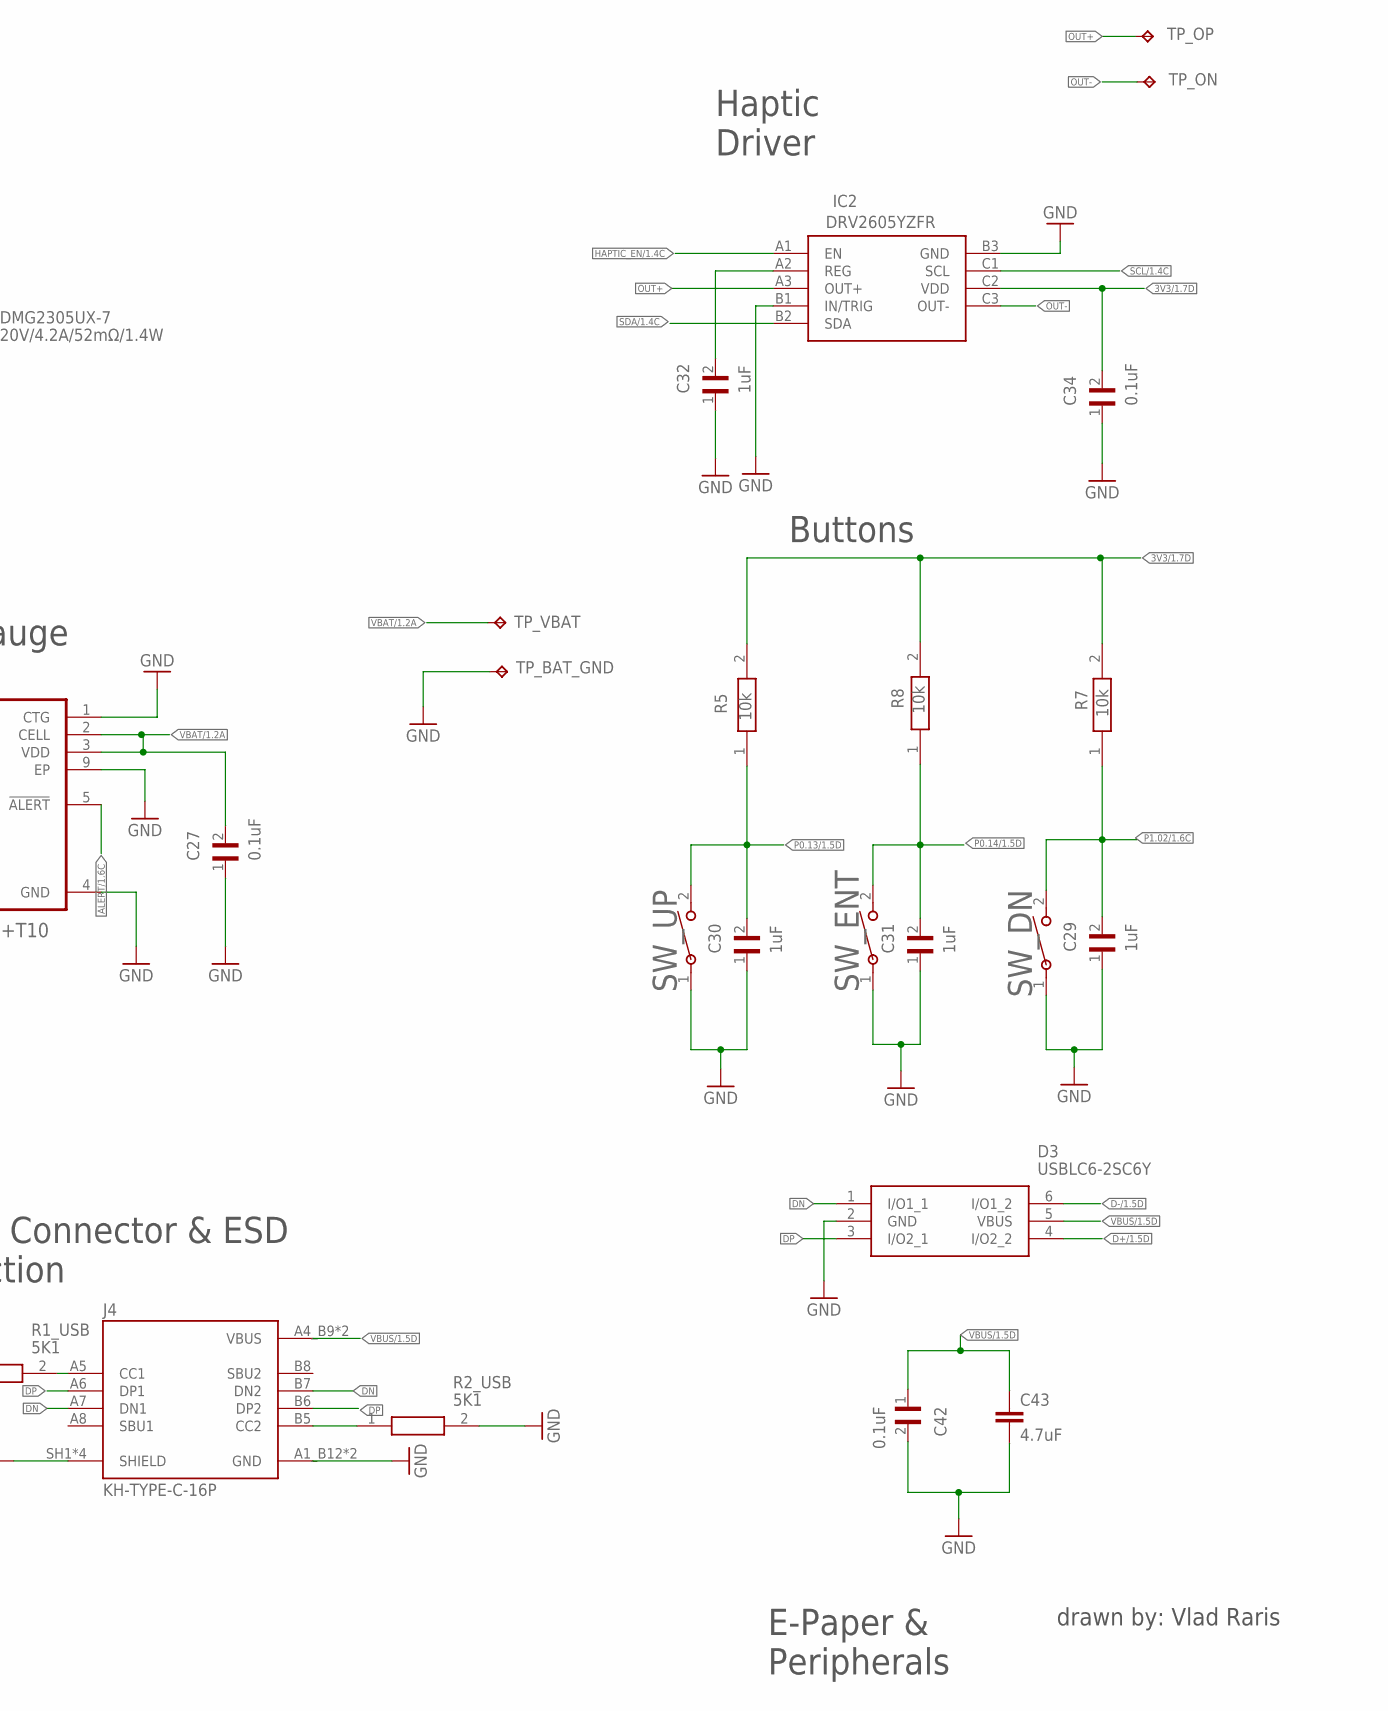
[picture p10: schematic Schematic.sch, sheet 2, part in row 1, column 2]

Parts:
C1-EP-DR: 10uF; NORDIC_NRF_3_RESC0201_L
C2-EP-DR: 4.7uF/25V; PERFECT_0402_0402
C27, C34, C42: 0.1uF; GRM011R60J152KE01L_2_CAPC0201X13N
C29, C30, C31, C32: 1uF; GRM011R60J152KE01L_2_CAPC0201X13N
C43: 4.7uF; PERFECT_0402_0402
D2, D4, D5: MBR0530; ESP32_C6_LIBRARY_5_SOD3716X135N
D3: USBLC6-2SC6Y; ESP32_C6_LIBRARY_3_SOT95P280X145-6N
DMG2305UX-7: 20V/4.2A/52mΩ/1.4W; ESP32_C6_LIBRARY_4_ESP32_C6_LIBRARY_4_ESP32_C6_LIBRARY_4_ES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
EPD_C1, EPD_C2, EPD_C6, EPD_C7, EPD_C8, EPD_C9, EPD_C10, EPD_C11, EPD_C12: 1uF/50V; PERFECT_0402_0402
EPD_C5: 0.1uF/50V; PERFECT_0402_0402
IC2: DRV2605YZFR; DRV2605YZFR_BGA9C50P3X3_144X144X62
J1: 503480-2400; 503480-2400_5034802400
J4: KH-TYPE-C-16P; KH-TYPE-C-16P_KINGHELM_KH-TYPE-C-16P
L5: 68uH; NORDIC_NRF_2_RESC0402_L
Q3: SI1308EDL-T1-GE3; ESP32_C6_LIBRARY_6_SOT65P210X110-3N
R1_EP_DR: 0.47; CPF0201D7K68C1_0201
R1_USB, R2_USB: 5K1; CPF0201D7K68C1_0201
R2_EP_DR: 10K; CPF0201D7K68C1_0201
R5, R7, R8: 10k; CPF0201D7K68C1_0201
R_PWR_EPD: 10K; CPF0201D7K68C1_0201
R_TYPE_SEL: 2.2; CPF0201D7K68C1_0201
SJ1: ESP32_C6_LIBRARY_7_JUMPER_SJ
SW_DN: 2025-10-22_07-23-44_LIBRARY_EVP-AKE31ASW_EVP-AKE3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; 2025-10-22_07-23-44_LIBRARY_SW_EVP-AKE31A_PAN
SW_ENT: 2025-10-22_07-23-44_LIBRARY_EVP-AKE31ASW_EVP-AKE3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; 2025-10-22_07-23-44_LIBRARY_SW_EVP-AKE31A_PAN
SW_UP: 2025-10-22_07-23-44_LIBRARY_EVP-AKE31ASW_EVP-AKE3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; 2025-10-22_07-23-44_LIBRARY_SW_EVP-AKE31A_PAN
TP_BAT_GND: HECTOR_WATCH_1_TPTP20R; HECTOR_WATCH_1_TP20R
TP_ON: HECTOR_WATCH_1_TPTP20R; HECTOR_WATCH_1_TP20R
TP_OP: HECTOR_WATCH_1_TPTP20R; HECTOR_WATCH_1_TP20R
TP_VBAT: HECTOR_WATCH_1_TPTP20R; HECTOR_WATCH_1_TP20R
U3: MAX17048G+T10; ESP32_C6_LIBRARY_SON50P200X200X80-9N

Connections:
3V3/1.7D: C34.2, IC2.C2 (VDD), R5.2, R7.2, R8.2, R_PWR_EPD.2
ALERT/1.6C: U3.5 (!ALERT)
D+/1.5D: D3.4 (I/O2_2)
D-/1.5D: D3.6 (I/O1_2)
DN: D3.1 (I/O1_1), J4.A7 (DN1), J4.B7 (DN2)
DP: D3.3 (I/O2_1), J4.A6 (DP1), J4.B6 (DP2)
EPD_3V3: C1-EP-DR.1, DMG2305UX-7.2 (S), DMG2305UX-7.3 (D), EPD_C5.2, J1.15, J1.16, L5.1
EPD_BUSY/1.5D: J1.9
EPD_CS/1.4C: J1.12
EPD_DC/1.5D: J1.11
EPD_RST/1.5D: J1.10
GDR: J1.2, Q3.1 (G), R2_EP_DR.2
GND: C1-EP-DR.2, C27.1, C29.1, C30.1, C31.1, C32.1, C34.1, C42.2, C43.2, D3.2 (GND), D4.1 (K), EPD_C1.1, EPD_C2.1, EPD_C5.1, EPD_C6.1, EPD_C7.1, EPD_C8.1, EPD_C9.1, EPD_C10.1, EPD_C11.1, EPD_C12.1, IC2.B1 (IN/TRIG), IC2.B3 (GND), J1.8, J1.17, J1.MP1, J1.MP2, J4.A1_B12 (GND), J4.A12_B1 (GND), J4.SH1 (SHIELD), J4.SH2 (SHIELD), J4.SH3 (SHIELD), J4.SH4 (SHIELD), R1_USB.1, R2_EP_DR.1, R2_USB.2, R_TYPE_SEL.1, SJ1.1, SW_DN.1, SW_ENT.1, SW_UP.1, TP_BAT_GND.TP, U3.1 (CTG), U3.4 (GND), U3.6 (QSTRT), U3.9 (EP); also elsewhere on the board
HAPTIC_EN/1.4C: IC2.A1 (EN)
MOSI/1.5B: J1.14
unnamed: C2-EP-DR.1, D2.1 (K), D4.2 (A)
unnamed: C2-EP-DR.2, D5.2 (A), L5.2, Q3.3 (D)
unnamed: J4.B5 (CC2), R2_USB.1
unnamed: R1_EP_DR.1, R_TYPE_SEL.2, SJ1.2
unnamed: C32.2, IC2.A2 (REG)
unnamed: J4.A5 (CC1), R1_USB.2
unnamed: EPD_C6.2, J1.18
unnamed: EPD_C7.2, J1.19
unnamed: EPD_C8.2, J1.20
unnamed: EPD_C10.2, J1.22
unnamed: EPD_C12.2, J1.24
unnamed: EPD_C2.2, J1.4
unnamed: EPD_C1.2, J1.5
OUT+: IC2.A3 (OUT+), TP_OP.TP
OUT-: IC2.C3 (OUT-), TP_ON.TP
P0.13/1.5D: C30.2, R5.1, SW_UP.2
P0.14/1.5D: C31.2, R8.1, SW_ENT.2
P1.01/1.6C: DMG2305UX-7.1 (G), R_PWR_EPD.1
P1.02/1.6C: C29.2, R7.1, SW_DN.2
PREVGH: D5.1 (K), EPD_C9.2, J1.21
PREVGL: D2.2 (A), EPD_C11.2, J1.23
RESE: J1.3, Q3.2 (S), R1_EP_DR.2
SCK/1.5B: J1.13
SCL/1.4C: IC2.C1 (SCL), U3.7 (SCL)
SDA/1.4C: IC2.B2 (SDA), U3.8 (SDA)
VBAT/1.2A: C27.2, TP_VBAT.TP, U3.2 (CELL), U3.3 (VDD)
VBUS/1.5D: C42.1, C43.1, D3.5 (VBUS), J4.A4_B9 (VBUS), J4.A9_B4 (VBUS)

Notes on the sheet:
E-Paper Drive Circuit
E-Paper & Peripherals
drawn by: Vlad Raris
E-Paper Display Connector
Fuel Gauge
Buttons
USB C Connector & ESD Protection
Haptic Driver

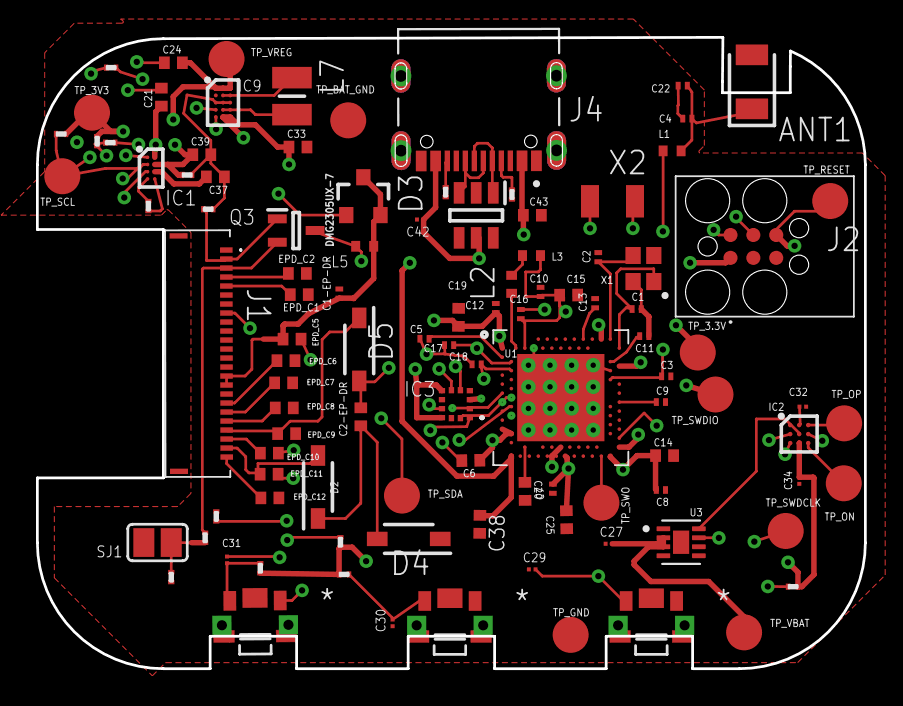
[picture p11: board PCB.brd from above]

Board: 4 copper layers, 46.0 x 35.1 mm, 105 parts (0 on the bottom side), 65 nets.

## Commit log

2026-04-10 Enhance README with images and PCB layout info
    Added images and updated PCB layout details in README.
2026-04-21 Add BOM.bom file to Manufacturing directory
2026-04-21 Rename WhatsApp Image 2026-04-21 at 11.17.51.jpeg to PCB3D

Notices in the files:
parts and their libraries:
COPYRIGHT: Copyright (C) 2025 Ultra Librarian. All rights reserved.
